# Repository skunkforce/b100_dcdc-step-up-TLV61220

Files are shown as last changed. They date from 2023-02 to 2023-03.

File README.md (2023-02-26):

# edgy_board number b100
This design is part of the [edgy board project](https://github.com/skunkforce/edgy_boards).

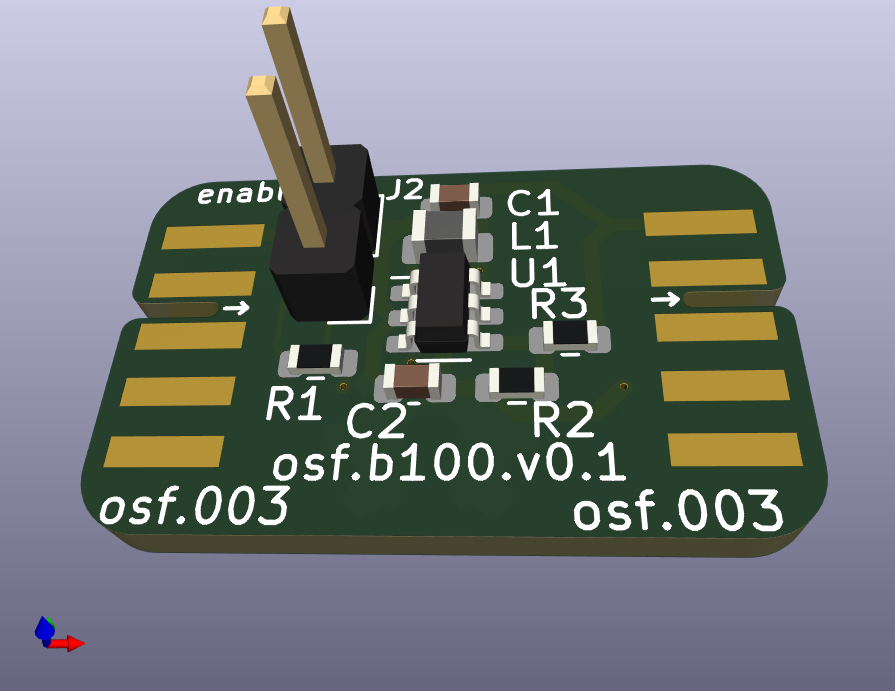
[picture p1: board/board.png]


# getting started
This repository uses submodules. After cloning use the command 

```$ git submodule update --init --recursive```

to pull the submodules before opening the project with kicad. 

# Tests
Tests can be found in [TESTS.md](TESTS.md)

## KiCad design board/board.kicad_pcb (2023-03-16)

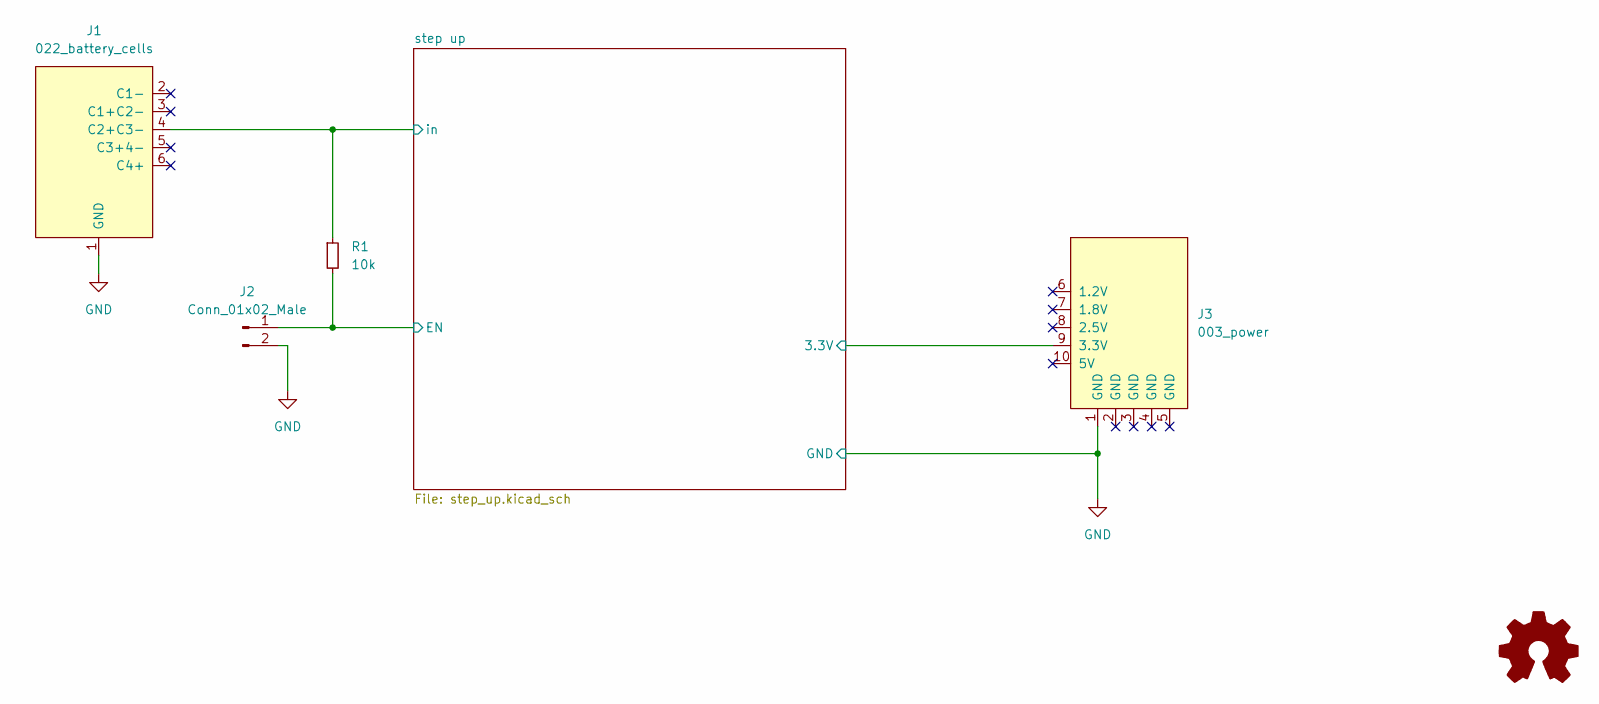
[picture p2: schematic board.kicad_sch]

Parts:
J1: 022_battery_cells; on_edge_2x05_device
J2: Conn_01x02_Male; PinHeader_1x02_P2.54mm_Vertical
J3: 003_power; on_edge_2x05_host
LOGO1: Logo_Open_Hardware_Small; OSHW-Symbol_6.7x6mm_SilkScreen
R1: 10k; R_0603_1608Metric

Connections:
/step up/3.3V: J3.9 (3.3V); also elsewhere on the board
/step up/EN: J2.1, R1.2; also elsewhere on the board
/step up/in: J1.4 (C2+C3-), R1.1; also elsewhere on the board
GND: J1.1 (GND), J2.2, J3.1 (GND); also elsewhere on the board

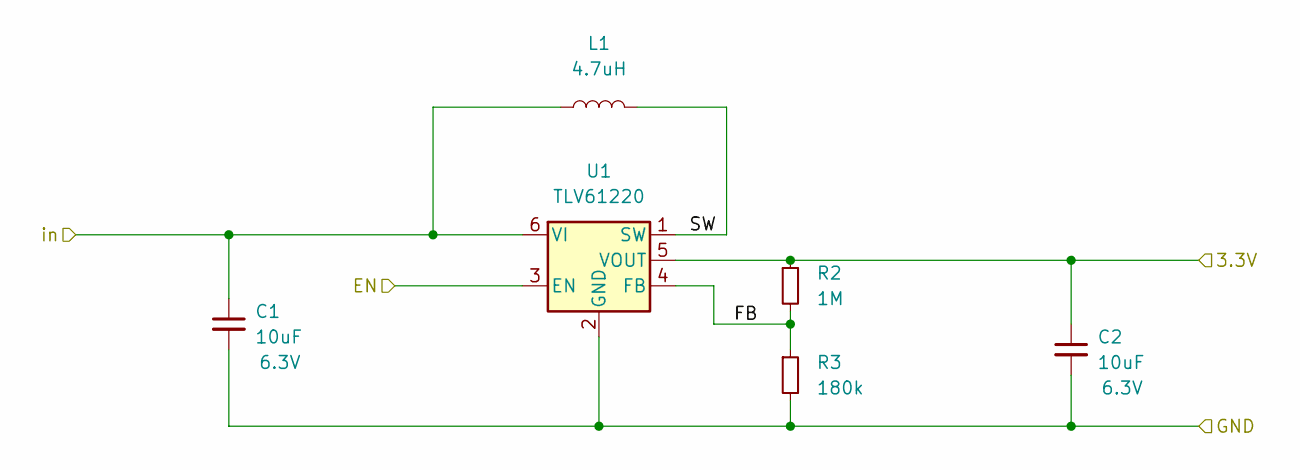
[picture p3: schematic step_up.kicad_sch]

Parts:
C1, C2: 10uF; C_0603_1608Metric; Voltage 6.3V
L1: 4.7uH; L_0805_2012Metric; MPN MLZ2012N4R7LTD25; DigiKey_PN 445-16383-1-ND
R2: 1M; R_0603_1608Metric
R3: 180k; R_0603_1608Metric
U1: TLV61220; SOT-23-6

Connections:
/step up/3.3V: C2.1, R2.1, U1.5 (VOUT); also elsewhere on the board
/step up/EN: U1.3 (EN); also elsewhere on the board
/step up/FB: R2.2, R3.1, U1.4 (FB)
/step up/SW: L1.2, U1.1 (SW)
/step up/in: C1.1, L1.1, U1.6 (VI); also elsewhere on the board
GND: C1.2, C2.2, R3.2, U1.2 (GND); also elsewhere on the board

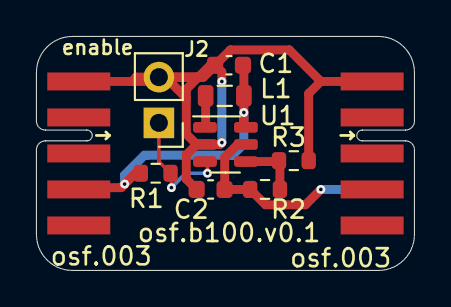
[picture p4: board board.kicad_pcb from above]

Board: 2 copper layers, 21.0 x 13.0 mm, 11 parts (1 on the bottom side), 6 nets.

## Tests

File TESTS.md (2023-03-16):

# sanity test

## setup

Connect 1.8v to pin 4 and gnd to pin 1 of the input connector (J1). Power consumption should be only a few milliampere.

## results

consumption less than 1ma.

# shutdown test

## setup

connect the two pins of the pinheader (J2) together and unpopulate R1. Output voltage should be no higher than input voltage and Power consumption should be only a few microvolts.

## results

works as expected.

# full power test

## setup

Connect 2.2v to pin 4 and gnd to pin 1 of the input connector. Connect a variable resistor between the output (pin 9 of J3) and GND. Start at 1k and adjust the resistor down to about 40R noting the output voltage (pin 9 to pin 1 of J3) at different intervalls.

## results

| current | ripple voltage | output voltage drop |
| --- | --- | --- |
| 1ma | 150mv | 0mv |
| 33ma | 200mv | 0mv |
| 66ma | 200mv | 0mv |
| 100ma | 190mv | 0mv |
| 110ma | 150mv | 50mv |
| 130ma | 150mv | 150mv |

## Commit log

2023-03-02 moved components for better EMC
    [board.kicad_pcb, board.kicad_sch, step_up.kicad_sch]
2023-03-04 changed input to battery cell connector
    [board.kicad_pcb, board.kicad_sch]
